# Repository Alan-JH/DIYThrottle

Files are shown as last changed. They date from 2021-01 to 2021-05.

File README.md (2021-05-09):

# DIYThrottle
Flight sim throttle design

I probably wont be uploading better documentation, as it is more difficult and boring than I expected. Sorry.

Version numbers are from Fusion, so they may not increase one by one.

Hats are JFlyer81's 4/5 way hats: https://www.thingiverse.com/thing:4543158

Two way switch on the middle finger is a modified version of Huzarski's hat switch (namely, it is a modified version of his "Body #B" which can be used for 2 or 3 way switches: https://www.thingiverse.com/thing:3641494

Grip is heavily modified from Olukelo's design: https://github.com/o-devices/throttle-quadrant 

Namely, modifications include:

a TDC slew instead of pushbutton for index finger

split throttle design

removal of the two potentiometers on the pinkie and middle finger in favor of a pushbutton and a 2/3 way hat

Re-arrangement of the hats and removal of one of the two buttons on the right side to fit the TDC slew

simple latching mechanism

Addition of screw and nut holes for M4 and M2 nuts and bolts to keep the grip together, as well as four M2.5-M3 screws for the latching mechanism

**Current BOM:**

4x 6802ZZ Bearings for the two arms

2x 685ZZ Bearings for the detent rollers

2x 5x5x10mm neodymium magnets

2x KMA 210 Magnoresistive sensors

2x RC shocks for damping (130mm between centers of mounting holes, remove springs, recommend using 70wt shock oil)

Assorted M5, M4, M3, M2, M2.5 (optional) nuts and bolts of lengths ranging from 8 to 20mm for the M2-M4 bolts and 8 to 40mm for the M5 bolts. I will provide a complete count soon (TM). The better assembly files have screws in them, you can count for yourself.

2x 0.6x7x25mm expansion springs with hooks for the fingerlifts

Approx 2x 30x45mm and 2x 30x40mm felt pads for friction pads, recommend greasing with Nyogel 767A

Loads of PETG filament

Alps RKJXV1224005 analog ministick + PCB (files included)

Shift register board (PCB files included)

15-18 6x6x4.3mm tact switches

2x 20mm endstop switches for OFF/IDLE binds, 4x 20mm endstop switches for hook and gear levers by JumpNShootMan (https://www.thingiverse.com/thing:4645392)

2x OTTO P1-1 or P3-1 Pushbutton (2.5lb actuation recommended)

a cheap ebay pushbutton with no tactile feedback for the pinkie button

2020 Extrusion corners

M5 and M4 T nuts and screws

approx 3.7m of 2020 extrusion, some with ends tapped

T plates

Bessey STC-IHH 25 toggle clamp

Assorted 12mm toggle switches (8 ON/OFF and 3 ON/OFF/ON)

Assorted buttons (I am using a pair of ebay pushbuttons and a sanwa arcade button for eject)

Jumpnshootman's gear and hook levers: https://www.thingiverse.com/thing:4645392

Shield: [][cc-by-nc-sa]

This work is licensed under a
[Creative Commons Attribution-NonCommercial-ShareAlike 4.0 International License][cc-by-nc-sa].

[][cc-by-nc-sa]

[cc-by-nc-sa]: http://creativecommons.org/licenses/by-nc-sa/4.0/
[cc-by-nc-sa-image]: https://licensebuttons.net/l/by-nc-sa/4.0/88x31.png
[cc-by-nc-sa-shield]: https://img.shields.io/badge/License-CC%20BY--NC--SA%204.0-lightgrey.svg

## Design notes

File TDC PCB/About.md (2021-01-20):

Simple PCB design for the RKJXV1224005 used for TDC slew. Oversized by accident, but I designed the grip around this. 

Lower corner facing the side panel of the grip needs to be snipped off

I'll probably edit the design before release to use a more reasonably sized PCB

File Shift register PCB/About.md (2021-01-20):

3 74HC165 Shift registers on a PCB, with pullups to 5V. CPL and BOM files included for SMT assembly

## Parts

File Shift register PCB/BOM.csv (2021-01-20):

ID | Name | Designator | Footprint | Quantity | Manufacturer Part | Manufacturer | Supplier | Supplier Part
1 | SOIC-16_L9.9-W3.9-P1.27-LS6.0-BL | SR1,SR2,SR3 | SOIC-16_L9.9-W3.9-P1.27-LS6.0-BL | 3
2 | R1206 | R1,R2,R3,R4,R5,R6,R7,R8,R9,R10,R11,R12,R13,R14,R15,R16,R17,R18,R19,R20,R21,R22,R23,R24 | R1206 | 24
3 | C0402 | C1,C2,C3 | C0402 | 3

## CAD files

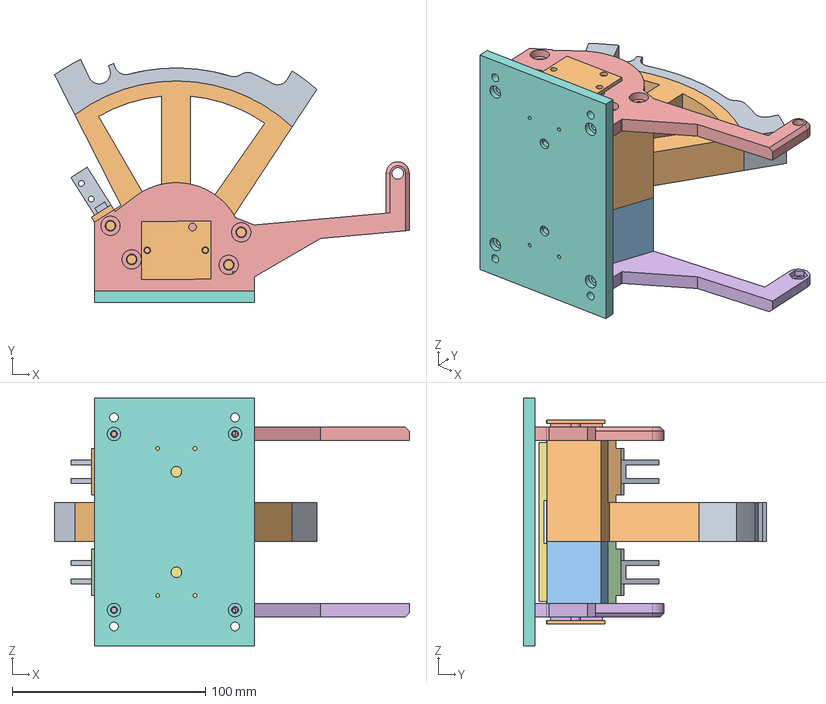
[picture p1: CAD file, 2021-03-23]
Detent track v74.step
183.5 x 125.8 x 128.0 mm
Profile
Track Structure
Forward Left structural part
Aft Left structural part
Right frame
Left frame
Friction adjustment pads
Friction adjustment lower plate
Endstop mount 1
Endstop mount 2
Sensor holdback x 2

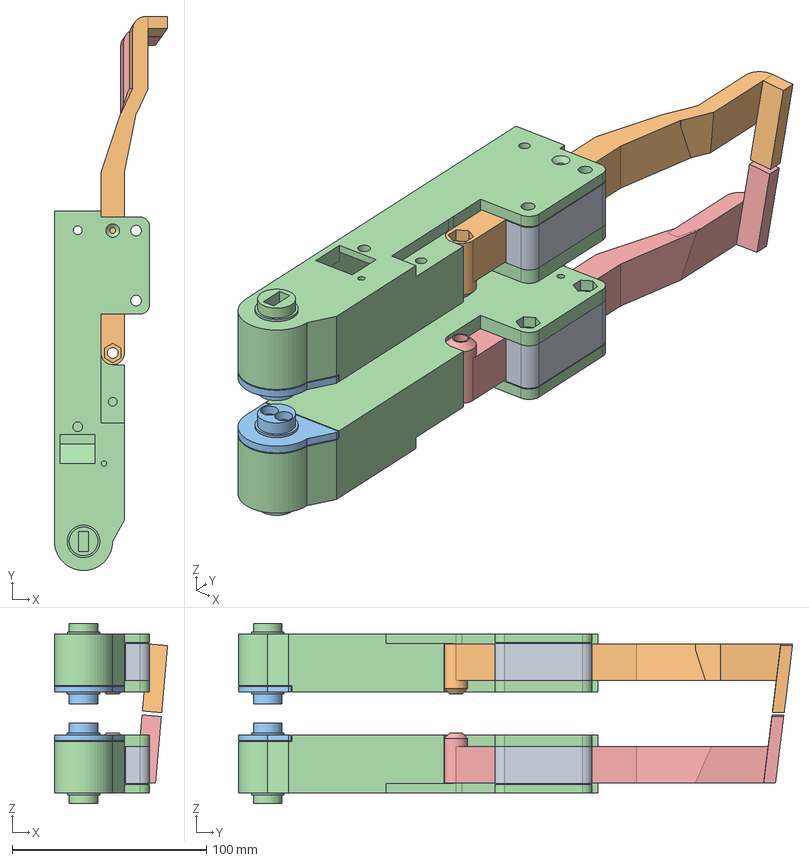
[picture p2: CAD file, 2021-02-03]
Arm v43.step
58.2 x 285.0 x 92.8 mm
Component1(Mirror)
Component2(Mirror)
Component3(Mirror)

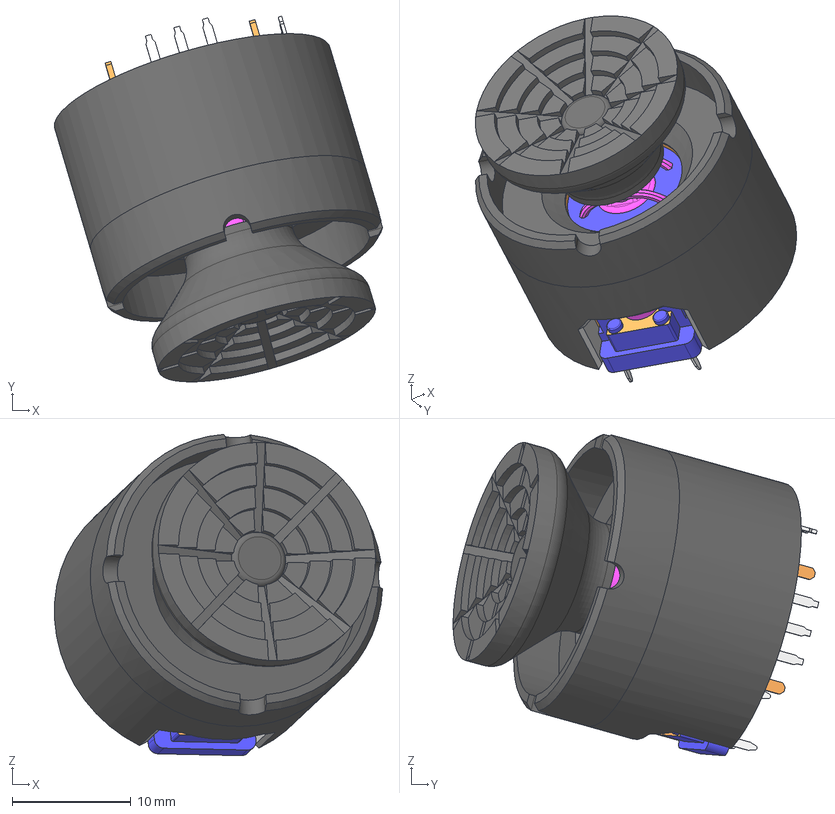
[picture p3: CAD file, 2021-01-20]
TDC slew v2.step
27.7 x 30.8 x 27.1 mm
TDC Switch Body
Lower TDC Switch Body
TDC Switch Cap
RKJXV1224005

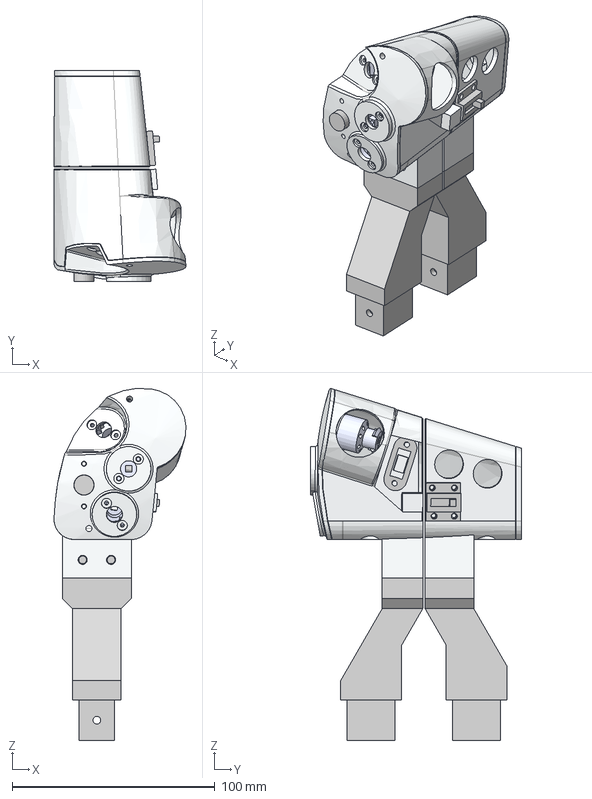
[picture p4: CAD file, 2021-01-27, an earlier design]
Old Versions/Grip v56.step
65.0 x 104.0 x 173.5 mm
Right half
Left half
side-panel
Bottom right
Bottom left
small-side-pane
Right Connector
Left connector
Two way
Hat top
Hat bottom
Hat middle
Latch body
Slider
Button
Tact switch nubbin

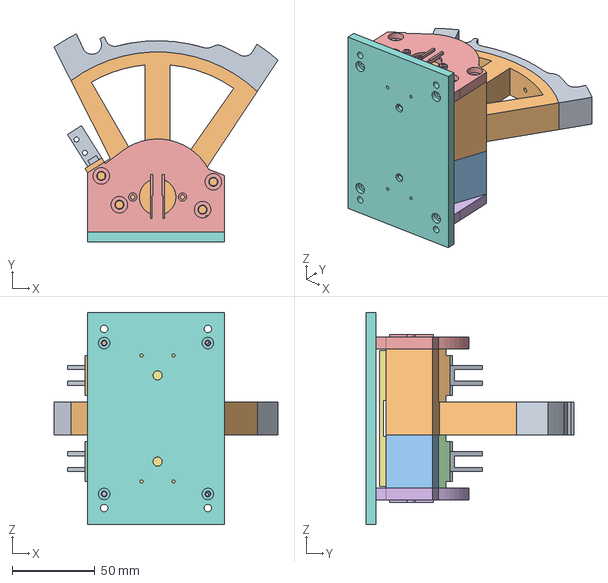
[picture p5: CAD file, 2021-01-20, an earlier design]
Old Versions/Detent track v68.step
135.1 x 125.6 x 128.0 mm

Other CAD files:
Old Versions/Detent track v72.step
Detent track v72.step
Old Versions/Detent track v71.step
Detent track v71.step
Old Versions/Detent track v69.step
Old Versions/Grip v55.step
Old Versions/Arm v41.step
Old Versions/Grip v54.step

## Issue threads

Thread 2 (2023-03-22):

Capacitor and resistor values

edwardker, 2023-03-22:
Hi,
Any chance you could let us noobs know which values you use for the resistors and the capacitors for your nice pcb?
Thanks for your support

Alan-JH, 2023-03-24:
The shift register PCB uses 10K 1206 resistors for pullups and 0.1uF 0603
capacitors. Though the PCB design is not good, as it's a v2 that I never
fabbed with the capacitors on the legs of the shift registers.

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

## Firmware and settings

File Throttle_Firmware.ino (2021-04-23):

//Firmware for Tacsim throttle
//Alan H.
//23 April 2021

//Libraries:
//bbSPI for using shift registers by Nick Gammon http://www.gammon.com.au/Arduino/bitBangedSPI.zip
//MHeironimus Joystick library https://github.com/MHeironimus/ArduinoJoystickLibrary (Plus a modification to allow 8 axes in Win10 https://github.com/MHeironimus/ArduinoJoystickLibrary/issues/177)
//MCP3208 Library by labfruits https://github.com/labfruits/mcp320x
#include <Joystick.h>
#include <bitBangedSPI.h>
#include <Mcp320x.h>
#include <SPI.h>

//CHANGE SETTINGS HERE

//FORMAT: string divided by commas, first section classification, second and third section are buttons it binds to (except for encoders)
//Classification: 
//0 unassigned (put whatever for the second and third sections, it doesn't matter)
//1 button (binding section is 2nd index normal bind, 3rd section secondary bind, which is pressed at the same time. -1 if unused)
//2 toggle (binding section is 2nd index normal bind, 3rd section secondary bind, which is pressed at the same time. -1 if unused)
//3 on and off toggle (binding section should be 2nd index ON bind, and 3rd index OFF bind. -1 if either is unused, e.g. {3,-1,25} means a toggle that pulses button 25 when toggled OFF, and nothing when toggled ON)
//4 encoder (binding section should be 2nd index normal bind, and 3rd index HARDWARE COUNTERPART (CW position if the assigned button is CCW, and vice versa), 1 indexed for consistency (i.e. first hardware button = 1, second is 2, etc.). 
int digitalpins[72][3] = { //Array of length the number of buttons on the shift registers, values are the digital pins they map to. SOFTWARE BUTTONS ARE ZERO INDEXED
  {3,21,22}, //1
  {3,23,24},
  {3,27,29},
  {3,28,30}, //4
  {0,0,0},
  {1,5,-1},
  {1,3,-1},
  {1,4,-1}, //8
  {0,0,0},
  {1,41,-1},
  {1,40,-1},
  {1,25,-1}, //12
  {3,32,33}, 
  {3,34,35},
  {3,36,38},
  {3,37,39}, //16
  {0,0,0}, 
  {1,44,-1},
  {1,47,-1},
  {0,0,0}, //20
  {4,45,22},
  {4,46,21},
  {4,42,24},
  {4,43,23}, //24
  {3,49,-1},
  {3,62,63},
  {3,64,65},
  {3,60,61}, //28
  {3,52,53},
  {3,51,-1},
  {3,54,55},
  {3,56,57}, //32
  {3,50,-1},
  {1,66,-1},
  {3,48,-1},
  {3,58,59}, //36
  {0,0,0},
  {1,68,-1},
  {1,69,-1},
  {1,67,-1}, //40
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
  {1,19,-1}, //Grip binds
  {1,18,-1},
  {1,20,-1},
  {1,17,-1}, //52
  {1,13,-1},
  {1,14,-1},
  {1,15,-1},
  {1,16,-1}, //56
  {0,0,0},
  {0,0,0},
  {0,0,0},
  {0,0,0}, //60
  {0,0,0},
  {1,6,-1},
  {1,8,-1},
  {1,7,31}, //64; bind 8 and 32 to this section, for discord VC (discord doesnt tell the difference between devices, so having two buttons (one of which is much higher than what most other devices have) combined makes sure I don't accidentally activate PTT)
  {0,0,0},
  {1,2,-1},
  {1,1,-1},
  {1,0,-1}, //68
  {1,9,-1},
  {1,10,-1},
  {1,11,-1},
  {1,12,-1} //72
}; 


//Encoders. Format: hardware pin 1, hardware pin 2, software pin 1, software pin 2. Hardware pins are 1-indexed, software pins are 0-indexed
int encoders[6][4] = { //Six encoders, because why not (I only used two)
  {21, 22, 45, 46},
  {23, 24, 42, 43},
  {0,0,0,0},
  {0,0,0,0},
  {0,0,0,0},
  {0,0,0,0},
};

unsigned long encoderTimers[6]; //Times for encoder buttons to deactivate, in milliseconds


#define TOGGLE_DELAY 60 //Delay in ms
#define ENCODER_DELAY 60 //Delay in ms

#define NUMSR 9 //Number of daisy chained shift registers

//Define Shift Register pins
bitBangedSPI bbSPI (bitBangedSPI::NO_PIN, A2, 15);  // MOSI, MISO, SCK (No connect, data, clock)

const int LATCH = A3; //AKA Load or "CS"

//Axis data struct
struct axis{
  String label;
  int range[3];
  int centerdeadzone;
};
//Define Axis spec
axis ADCChannels[8] = { //Label, Range {min, center (-1 for no center), max} or {max, center (-1 for no center), min} if inverted, Center deadzone (both sides)
  {"z", {2486, -1, 1504}, 0}, //right throttle
  {"rz", {1582, -1, 2571}, 0}, //left throttle
  {"ry", {3079, 2135, 1231}, 150}, //TDC slew vertical
  {"rx", {3132, 2207, 1190}, 150}, //TDC slew horizontal
  {"rudder", {0, -1, 4095}, 0}, //knob 3
  {"throttle", {0, -1, 4095}, 0}, //knob 4
  {"x", {0, -1, 4095}, 0}, //knob 1
  {"y", {0, -1, 4095}, 0} //knob 2
};


#define FILTER 6 //Filter amount for all axes.
#define MAINRELDZ  50  //Main axis relative deadzone (on each side)(keeps the two axes the same value if they are within this amount of each other)


//Define ADC
#define SPI_CS      8       //SPI slave select
#define ADC_VREF    5000    //5V Vref
#define ADC_CLK     1600000 //SPI clock 1.6Mhz

MCP3208 adc(ADC_VREF, SPI_CS);

//JOYSTICK SETTINGS
Joystick_ Joystick(JOYSTICK_DEFAULT_REPORT_ID,
  JOYSTICK_TYPE_JOYSTICK,
  70, //number of buttons
  0, //number of hat switches
  //Set as many axis to "true" as you have potentiometers for
  true, // y axis
  true, // x axis
  true, // z axis
  true, // rx axis
  true, // ry axis
  true, // rz axis
  true, // rudder
  true, // throttle
  false, // accelerator
  false, // brake
  false); // steering wheel
  
//END CHANGE SETTINGS

SPISettings settings(ADC_CLK, MSBFIRST, SPI_MODE0);

void setup() {
  // put your setup code here, to run once:
  // initialize serial
  Serial.begin(115200);
  
  Serial.println ("Initializing");
  
  //Shift registers:
  bbSPI.begin ();
  pinMode (LATCH, OUTPUT);
  digitalWrite (LATCH, HIGH);

  //ADC:
  // configure PIN mode
  pinMode(SPI_CS, OUTPUT);

  // set initial PIN state
  digitalWrite(SPI_CS, HIGH);
  
  // Initialize Joystick
  Joystick.begin();

  //Set axis ranges
  Joystick.setYAxisRange(ADCChannels[7].range[0], ADCChannels[7].range[2]);
  Joystick.setXAxisRange(ADCChannels[6].range[0], ADCChannels[6].range[2]);
  Joystick.setZAxisRange(ADCChannels[0].range[0], ADCChannels[0].range[2]);
  Joystick.setRxAxisRange(ADCChannels[3].range[0], ADCChannels[3].range[2]);
  Joystick.setRyAxisRange(ADCChannels[2].range[0], ADCChannels[2].range[2]);
  Joystick.setRzAxisRange(ADCChannels[1].range[0], ADCChannels[1].range[2]);
  Joystick.setRudderRange(ADCChannels[4].range[0], ADCChannels[4].range[2]);
  Joystick.setThrottleRange(ADCChannels[5].range[0], ADCChannels[5].range[2]);
  //End of setup
}

//Arrays with shift register states
byte SRStates[NUMSR];
byte oldSRStates[NUMSR]; // previous state
bool SRState1D[8*NUMSR + 1]; //state but each button has its own index in the array
bool oldSRState1D[8*NUMSR + 1]; //old state but each button has its own index in the array

//Arrays with previous axis readings to average for filtering.
uint16_t previousAxisVals[8][FILTER];
int nextAvgIndex[8];

void updateButtonValue(int hwbutton, byte buttonState, byte oldState){
  byte type = digitalpins[hwbutton-1][0];
  switch (type){
    case 0: //Unused button
      break;
    case 1: //Normal button
      if (buttonState == 0){ //LOW state means button is pressed, with pullups
        Joystick.pressButton(digitalpins[hwbutton-1][1]); //Press button
        if (digitalpins[hwbutton-1][2] != -1){ //Check if secondary button is assigned
          Joystick.pressButton(digitalpins[hwbutton-1][2]);
        }
      }else{ //HIGH state means button is released, with pullups
        Joystick.releaseButton(digitalpins[hwbutton-1][1]); //Release button
        if (digitalpins[hwbutton-1][2] != -1){ //Check if secondary is assigned
          Joystick.releaseButton(digitalpins[hwbutton-1][2]); 
        }
      }
      break;
    case 2: //Toggle
      //if ((buttonState == 0 && oldState == 1) || (buttonState == 1 && oldState == 0)){ //Button state has changed
      Joystick.pressButton(digitalpins[hwbutton-1][1]); //Press button
      if (digitalpins[hwbutton-1][2] != -1){ //Check if secondary button is assigned
        Joystick.pressButton(digitalpins[hwbutton-1][2]);
      }
      delay(TOGGLE_DELAY); //Keep pressed for given amount of time
      Joystick.releaseButton(digitalpins[hwbutton-1][1]); //Release button
      if (digitalpins[hwbutton-1][2] != -1){ //Check if secondary button is assigned
        Joystick.releaseButton(digitalpins[hwbutton-1][2]);
      }
      //}
      break;
    case 3: //Toggle ON and OFF
      //if (buttonState == 0 && oldState == 1){  //Check if toggled on and button is assigned
      if (buttonState == 0){
        if (digitalpins[hwbutton-1][1] != -1){
          Joystick.pressButton(digitalpins[hwbutton-1][1]); //Press button, wait, release
          delay(TOGGLE_DELAY); 
          Joystick.releaseButton(digitalpins[hwbutton-1][1]); 
        }
      //}else if (buttonState == 1 && oldState == 0){  //Check if toggled off and button is assigned
      }else{
        if (digitalpins[hwbutton-1][2] != -1){
          Joystick.pressButton(digitalpins[hwbutton-1][2]); //Press button, wait, release
          delay(TOGGLE_DELAY);
          Joystick.releaseButton(digitalpins[hwbutton-1][2]);
        }
      }
      break;
    /*case 4: //Encoder
      int counterhw = digitalpins[hwbutton-1][2]; //Get opposite direction pin state
      bool counterstate = SRState1D[counterhw];
      Serial.println(counterstate);
      if (!buttonState && counterstate){ //If this pin is closed and the other pin is open, the encoder is rotating in this direction
        Joystick.pressButton(digitalpins[hwbutton-1][1]); //Press, delay, release, ignoring possible turns within the delay.
        delay(ENCODER_DELAY);
        Joystick.releaseButton(digitalpins[hwbutton-1][1]);
      }
      break;*/ //Ignore this, this does not work
  }
  
}

void checkEncoders(){
  for (int i = 0; i < 6; i ++){ //check each encoder
    if (encoders[i][0] != 0){
      int hw1 = encoders[i][0];
      int hw2 = encoders[i][1];
      int sw1 = encoders[i][2];
      int sw2 = encoders[i][3];
      if (encoderTimers[i] != 0 && millis() >= encoderTimers[i]){
        Joystick.releaseButton(sw1);
        Joystick.releaseButton(sw2);
        encoderTimers[i] = 0;
      }
      if (encoderTimers[i] == 0 && SRState1D[hw1] == 0 && SRState1D[hw1] != oldSRState1D[hw1]){
        if (SRState1D[hw1] != SRState1D[hw2]){ //one direction
          Joystick.pressButton(sw1); //Press, delay, release, ignoring possible turns within the delay.
          encoderTimers[i] = millis() + ENCODER_DELAY;
          //delay(ENCODER_DELAY);
          //Joystick.releaseButton(sw1);
        }
      }else if (encoderTimers[i] == 0 && SRState1D[hw2] == 0 && SRState1D[hw2] != oldSRState1D[hw2]){
        if (SRState1D[hw2] != SRState1D[hw1]){//the other direction
          Joystick.pressButton(sw2); //Press, delay, release, ignoring possible turns within the delay.
          encoderTimers[i] = millis() + ENCODER_DELAY;
          //delay(ENCODER_DELAY);
          //Joystick.releaseButton(sw2);
        }
      }
    }
  }
}

uint16_t filteravg(int index, uint16_t raw){ //Running average filter
  previousAxisVals[index][nextAvgIndex[index]++] = raw; 
  if (nextAvgIndex[index] >= FILTER){ //Wrap index to add value around to the oldest value when the end is reached
    nextAvgIndex[index] = 0;
  }
  float runningAvg = 0;
  for (int i = 0; i < FILTER; i++){ //Average current contents of axis value buffer
    runningAvg += previousAxisVals[index][i];
  }
  runningAvg /= FILTER;
  return runningAvg;
}

void processAxis(int index, uint16_t rawval){
  axis axisinfo = ADCChannels[index];
  int16_t processed = filteravg(index, rawval); //Running average values
  //int16_t processed = rawval;
  if (axisinfo.range[1] != -1){ //Has center
    int16_t distToCenter = processed - axisinfo.range[1];
    int16_t softwarecenter = (axisinfo.range[2]+axisinfo.range[0])/2;
    if (abs(distToCenter) < axisinfo.centerdeadzone){ //Axis is within center dead zone
      processed = softwarecenter;
    }else if (distToCenter > 0){ //Axis is greater than center
      processed = map(processed, axisinfo.range[1] + axisinfo.centerdeadzone, max(axisinfo.range[0], axisinfo.range[2]), softwarecenter, max(axisinfo.range[0], axisinfo.range[2]));
    }else if (distToCenter < 0){ //Axis is less than center
      processed = map(processed, axisinfo.range[1] - axisinfo.centerdeadzone, min(axisinfo.range[0], axisinfo.range[2]), softwarecenter, min(axisinfo.range[0], axisinfo.range[2]));
    }
  }

  
  if (axisinfo.label.equals("x")){ //Horrible horribleness to set axes because I can't be bothered to learn function pointers
    Joystick.setXAxis(processed);
  } else if (axisinfo.label.equals("y")){
    Joystick.setYAxis(processed);
  } else if (axisinfo.label.equals("z")){
    Joystick.setZAxis(processed);
  } else if (axisinfo.label.equals("rx")){
    Joystick.setRxAxis(processed);
  } else if (axisinfo.label.equals("ry")){
    Joystick.setRyAxis(processed);
  } else if (axisinfo.label.equals("rz")){
    Joystick.setRzAxis(processed);
  } else if (axisinfo.label.equals("rudder")){
    Joystick.setRudder(processed);
  } else if (axisinfo.label.equals("throttle")){
    Joystick.setThrottle(processed);
  }
}

void loop() {
  // put your main code here, to run repeatedly:
  //Shift registers
  
  digitalWrite (LATCH, LOW);    // pulse parallel load latch
  digitalWrite (LATCH, HIGH);
  for (int i = 0; i < NUMSR; i++){ //Iterate through each SR and record the inputs
    SRStates[i] = bbSPI.transfer(0);
    byte mask = 1;
    for (int j = 1; j <= 8; j++) //Iterate through each input pin on the SR
      {
      SRState1D[8*i+j] = SRStates[i] & mask;
      if ((SRStates[i] & mask) != (oldSRStates[i] & mask))
        {
        Serial.print ("Switch ");
        Serial.print (8*i+j);
        Serial.print (" now ");
        Serial.println ((SRStates[i] & mask) ? "open" : "closed"); //This assumes pullup resistors
        
        updateButtonValue(8*i+j, SRStates[i] & mask, oldSRStates[i] & mask);
        
        }  // end of bit has changed
      
      mask <<= 1;  
      }  // end of for each bit
  }

  checkEncoders();

  for (int i = 0; i < NUMSR; i++){
    oldSRStates[i] = SRStates[i];
  }
  for (int i = 0; i < 8*NUMSR; i++){
    oldSRState1D[i] = SRState1D[i];
  }

  SPI.begin(); //Start SPI
  SPI.beginTransaction(settings);
  //Update axes
  for (int i = 0; i < 8; i++){
    //Array with channel definitions for ADC
    uint16_t raw;
    switch (i){
      case 0:
        raw = adc.read(MCP3208::Channel::SINGLE_0);
        //Serial.print("CH1 ");
        //Serial.println(raw);
        break;
      case 1:
        raw = adc.read(MCP3208::Channel::SINGLE_1);
        //Serial.print("CH2 ");
        //Serial.println(raw);
        break;
      case 2:
        raw = adc.read(MCP3208::Channel::SINGLE_2);
        //Serial.print("CH3 ");
        //Serial.println(raw);
        break;
      case 3:
        raw = adc.read(MCP3208::Channel::SINGLE_3);
        //Serial.print("CH4 ");
        //Serial.println(raw);
        break;
      case 4:
        raw = adc.read(MCP3208::Channel::SINGLE_4);
        //Serial.print("CH5 ");
        //Serial.println(raw);
        break;
      case 5:
        raw = adc.read(MCP3208::Channel::SINGLE_5);
        //Serial.print("CH6 ");
        //Serial.println(raw);
        break;
      case 6:
        raw = adc.read(MCP3208::Channel::SINGLE_6);
        //Serial.print("CH7 ");
        //Serial.println(raw);
        break;
      case 7:
        raw = adc.read(MCP3208::Channel::SINGLE_7);
        //Serial.print("CH8 ");
        //Serial.println(raw);
        break;
    }
    processAxis(i, raw);
  }
  SPI.endTransaction(); //End SPI to make sure it does not interfere with bit banged shift register SPI
  SPI.end();

  delay(1);
}

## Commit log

2021-01-20 WIP Files
    [Arm v41.step, Detent track v68.step, Grip v54.step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]
2021-01-25 Updated tolerances on the right panel
    [Grip v55.step]
2021-01-27 Ergonomic changes
    Angled top hat on right panel for better ergonomics, currently untested
    [Grip v56.step]
2021-01-27 Ergonomics changes
    Decided to use the same version number as before, but I changed a couple of the angles around. Still untested
    [Grip v56.step]
2021-02-01 Fixed middle finger hat
    Fixed an issue where the hole for the middle finger hat was too small, and added a model for the hat itself to the assembly.
2021-02-03 Added Dampers
    Added mounting points to use 130mm RC shocks (without springs) as a damper for the arms
    [Arm v43.step, Detent track v69.step]
2021-02-05 Updated left grip
    Properly sized the holes for the OTTO Pushbuttons, added a hole for an M2.5-M3 retaining screw + washer to hold it in.
2021-02-10 Hopefully final revision detent track
    Made the detent slightly harder
    [Detent track v71.step]
2021-02-10 Added dampers
    [Detent track v69.step]
2021-02-19 Added Sensor holdback plates
    Realized I forgot to add this, this should be the final revision, if all works well.
    [Detent track v72.step]
2021-03-11 Assembly file
    Not finished, everything is out of square by .1 degrees or so because of some weird geometry on the bottom plate.
2021-03-23 Aligned lower plate with XY plane
    previous versions were about 0.1 degrees out of square, so I aligned the lower plate with the XY plane to solve this. A new assembly version including this change will be made soon
    [Detent track v74.step]
2021-03-23 Rename Detent track v72.step to Old Versions/Detent track v72.step
    [Detent track v72.step]
2021-03-23 Archive Detent track v71
    [Detent track v71.step]
2021-03-24 Better Assembly with fasteners
    Added fasteners, bearings, springs, etc into the design. Also changed the colors to not be beige, and aligned the lower plate to be in square. Currently it is just the mechanism and not the frame, bu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
2021-03-28 Added RC shocks to assembly
    Added a rough representation of each RC shock for damping; these are the ones I used: https://www.amazon.com/gp/product/B01N0Y1DMK
2021-03-28 Aligned lower plate with XY plane
2021-04-23 Arduino Firmware
    This code is a weird mix between customizable and hard coded. Beware
    Also, the encoder function is a little inconsistent as I am not using hardware interrupts.

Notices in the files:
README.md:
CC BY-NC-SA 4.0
